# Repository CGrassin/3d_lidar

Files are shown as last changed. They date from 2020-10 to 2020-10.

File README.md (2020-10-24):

# 3D Lidar scanner

Lidars (LIgh Detection And Ranging) measure distances by illuminating the target with laser light and measuring the reflection with a sensor.

Link to the article: http://charleslabs.fr/en/project-3D+Lidar+Scanner+MK2

This is my 3D Lidar:
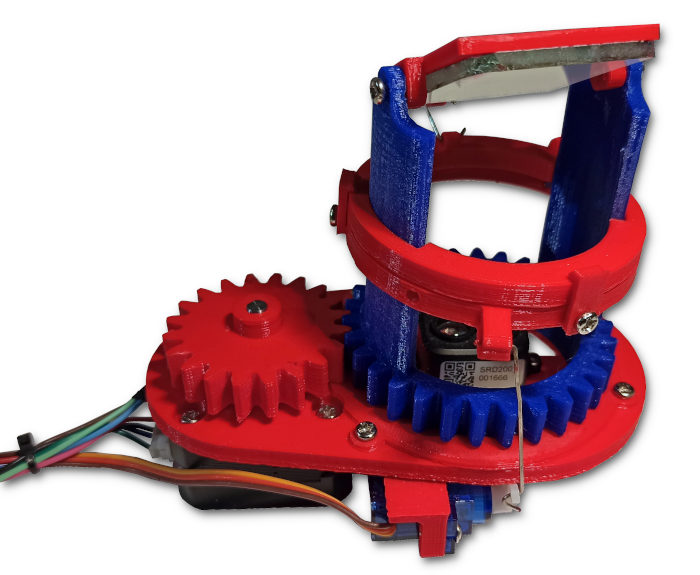
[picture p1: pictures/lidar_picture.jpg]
Picture of the 3D lidar


This repository contains the source files to build it:
* Mechanical: STL files for 3D-printing, linkages bending patterns and SolidWorks source files,
* Electronics: circuit diagram,
* Arduino code: the Arduino project for the micro-controller,
* Processing code: the LidarViewer Processing sketch.

## BOM

This is the projects' BOM:

| Quantity | Item | Total cost |
|---|---|---|
| 1 | STM32F103 board | $2 |
| 1 | Mini 360 DC Buck Converter | $1 |
| 1 | DRV8825 Stepper Motor Driver | $0.9 |
| 1 | TF-Luna LiDAR Range Finder Sensor Module | $20 |
| 1 | 17HS4023 stepper motor | $7.3 |
| 2 | 9g Sg90 Miniature Servo Motor | $2.6 |
| 1 | USB 2.0 to UART Serial Converter Module  | $1 |
| 15 | M3×6mm screw | $2 |
| 2 | M2.5 screw | $1 |
| / | PLA filament | About $3 |
| 1 | 40&times;40 piece of mirror | / |
| 1 | Breadboard | $1 |

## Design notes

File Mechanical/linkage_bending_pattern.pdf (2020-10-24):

# Linkages bending pattern

Servo linkage x2

40mm

5mm

3mm
3mm
Mirror linkage

12mm

10mm

10mm

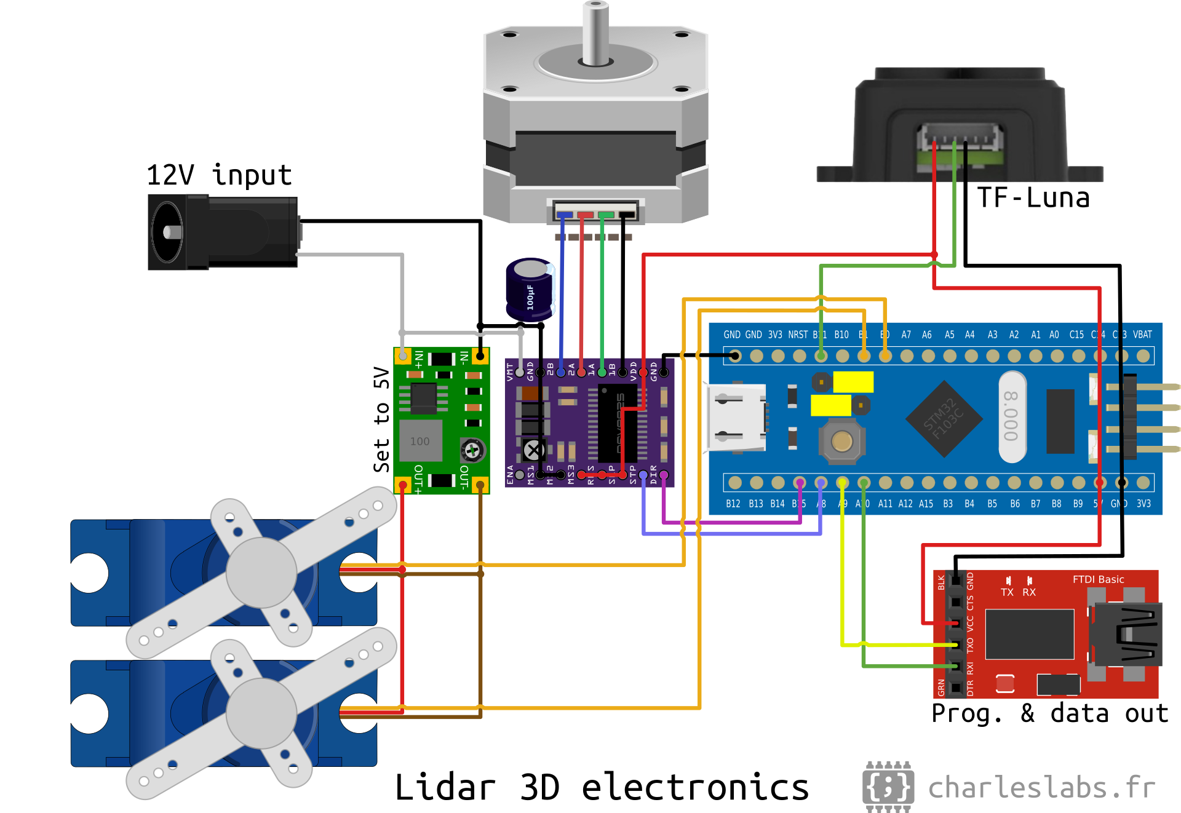
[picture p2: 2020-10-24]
Electronics/lidar_electronics.png

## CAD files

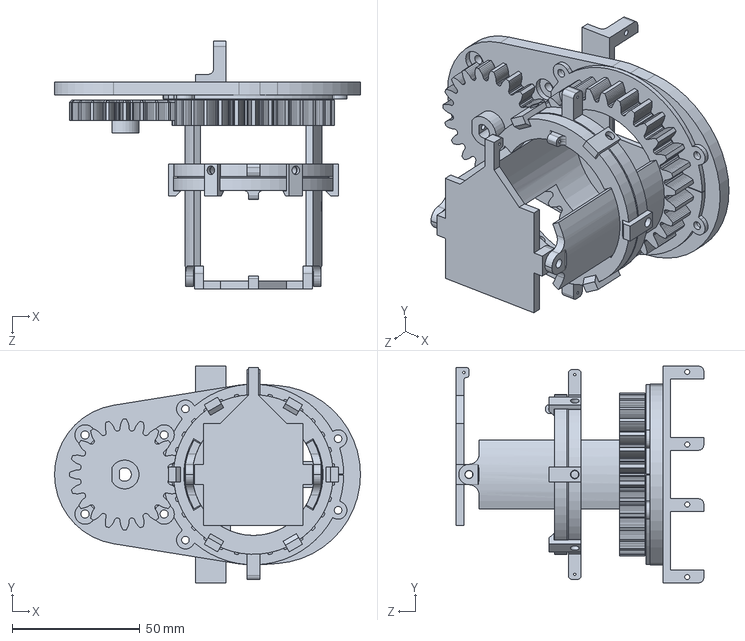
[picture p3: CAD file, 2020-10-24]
Mechanical/LidarMK2.SLDPRT
120.0 x 85.0 x 97.1 mm

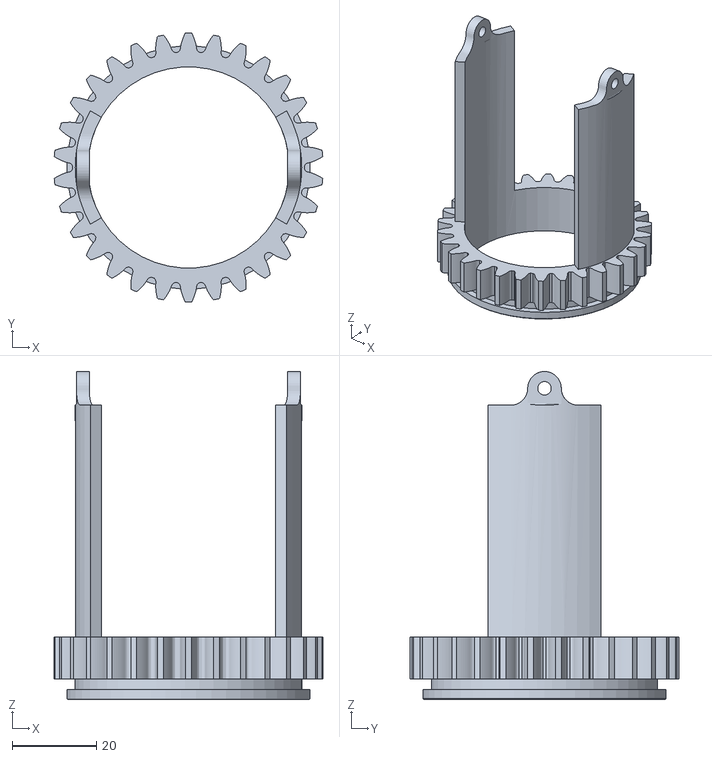
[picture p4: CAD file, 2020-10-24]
Mechanical/STL files/LidarMK2-Rotor.STL
63.8 x 64.0 x 77.9

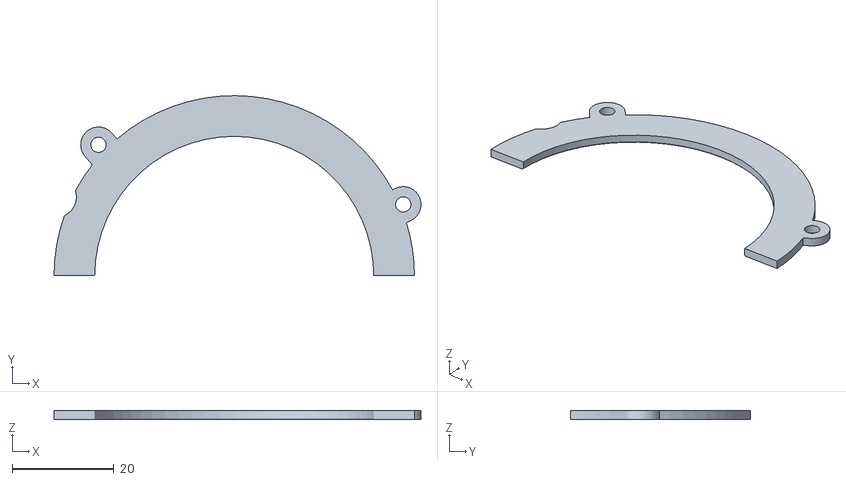
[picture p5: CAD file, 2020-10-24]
Mechanical/STL files/LidarMK2-Rotor _holder.STL
72.1 x 35.3 x 1.69

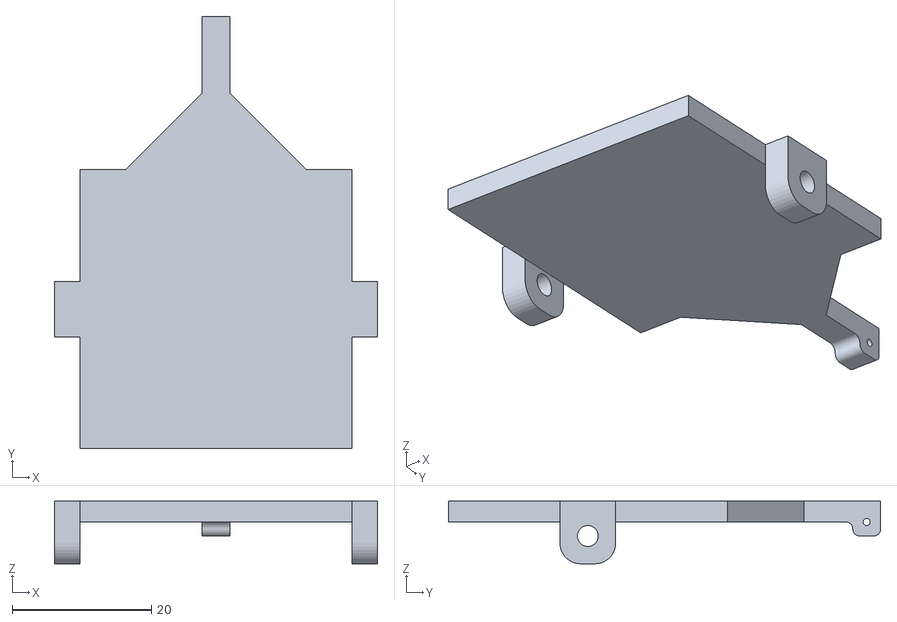
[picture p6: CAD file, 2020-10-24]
Mechanical/STL files/LidarMK2-Mirror.STL
46.3 x 62.0 x 9.00

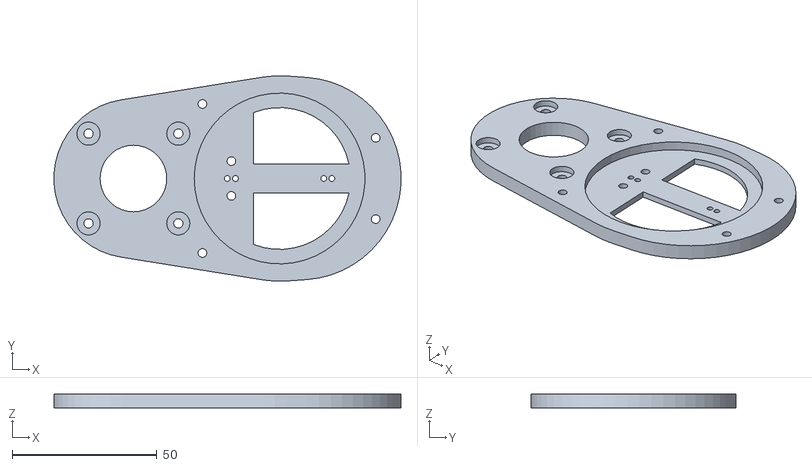
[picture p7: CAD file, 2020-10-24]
Mechanical/STL files/LidarMK2-Base.STL
119.9 x 70.9 x 5.00

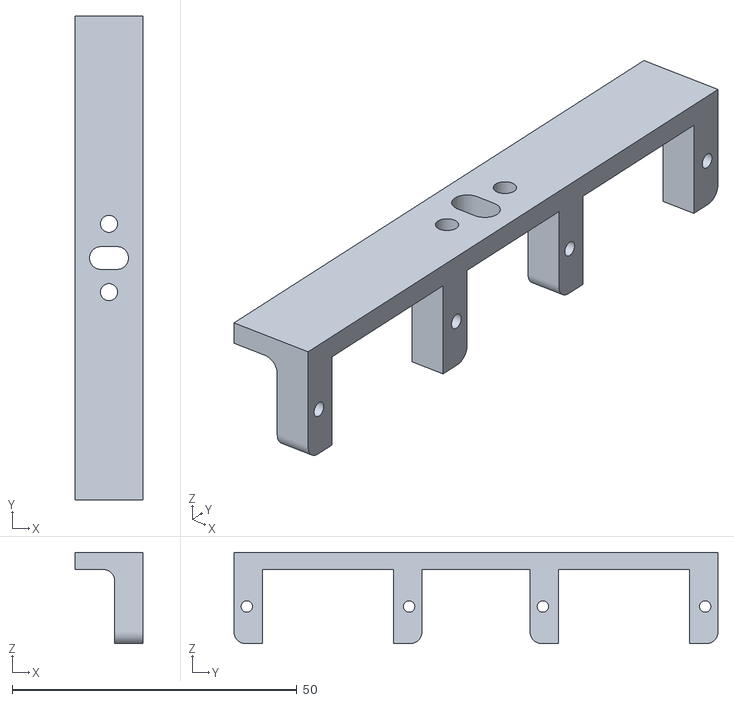
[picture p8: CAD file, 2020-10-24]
Mechanical/STL files/LidarMK2-Servos.STL
12.0 x 85.0 x 16.0

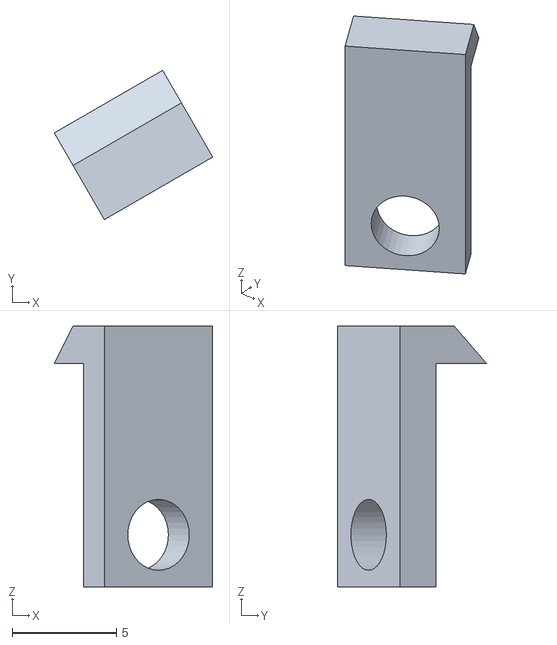
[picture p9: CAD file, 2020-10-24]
Mechanical/STL files/LidarMK2-Ring_link.STL
7.60 x 7.16 x 12.5

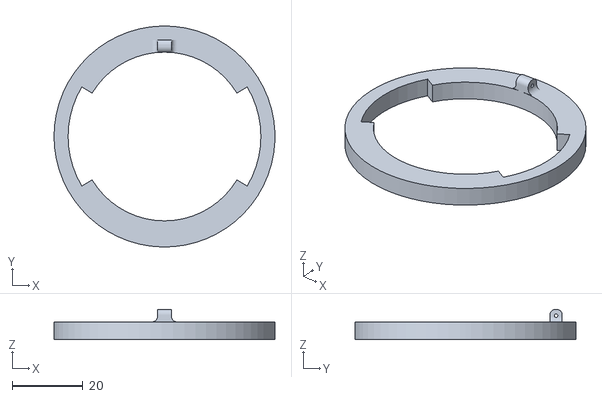
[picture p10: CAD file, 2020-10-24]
Mechanical/STL files/LidarMK2-Ring_top.STL
62.6 x 62.6 x 8.50

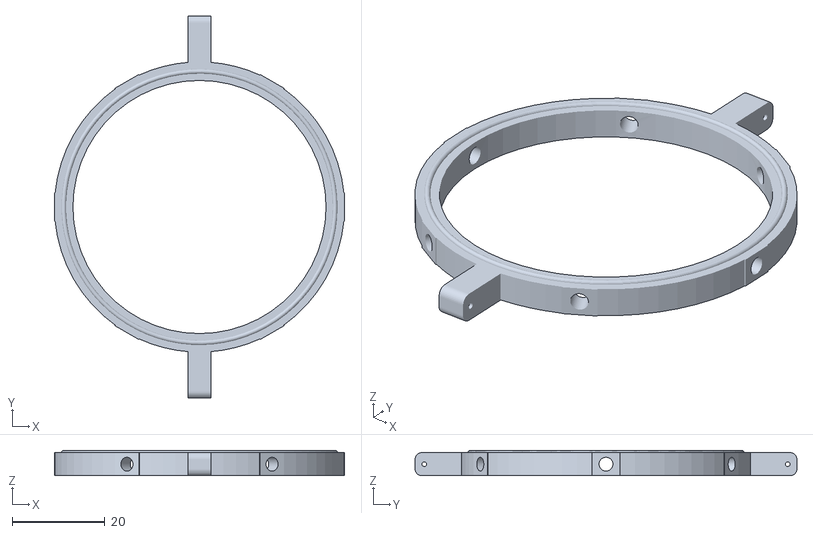
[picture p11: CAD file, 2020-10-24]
Mechanical/STL files/LidarMK2-Ring_bot.STL
62.6 x 82.4 x 5.50

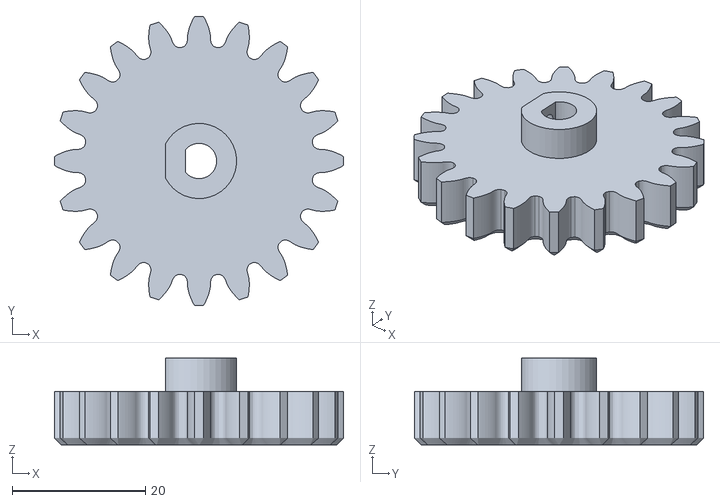
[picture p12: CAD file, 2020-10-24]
Mechanical/STL files/LidarMK2-GearMotor.STL
43.4 x 43.4 x 13.0

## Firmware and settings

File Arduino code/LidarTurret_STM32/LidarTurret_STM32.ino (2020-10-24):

// Includes
#include <Servo.h>

// TF-Mini or TF-Luna
#define TFMINI_BAUDRATE 115200 // bauds
#define TFMINI_DATARATE 10.0f // ms
int distance = 0;
int strength = 0;
float temp = 0;

// Servos
Servo servo_g, servo_d;
#define SERVO_G_PIN PB0
#define SERVO_D_PIN PB1
#define SERVO_POS_NEUTRAL 90
#define SERVO_POS_MIN SERVO_POS_NEUTRAL - 40
#define SERVO_POS_MAX SERVO_POS_NEUTRAL + 40
int servo_angle = SERVO_POS_MIN; // current servo pos

// Stepper
#define DIR_PIN PB15 
#define STEP_PIN PA8
#define PULSE_PER_REV 2400 // PPR_motor * Gear_reduction * Microstepping = 200*3/2*16
#define TIME_PER_REV 500.0f // ms
const int TIME_PER_PULSE = (TIME_PER_REV * 1000.0f)/ PULSE_PER_REV; // us
const int PULSE_PER_DATAPOINT = (TFMINI_DATARATE * 1000.0f) / TIME_PER_PULSE;

// External communication
#define EXTERNAL_BAUDRATE 115200 // bauds
char serial_buffer[15];
float theta,phi,rho;

// the setup function runs once when you press reset or power the board
void setup() {
  // Stepper
  pinMode(DIR_PIN, OUTPUT);
  pinMode(STEP_PIN, OUTPUT);
  digitalWrite(DIR_PIN,HIGH);
  
  // Servos
  servo_g.attach(SERVO_G_PIN);
  servo_d.attach(SERVO_D_PIN);
  servo_pos(servo_angle);
  
  // Serial ports
  Serial.begin(EXTERNAL_BAUDRATE); // USB
  Serial3.begin(TFMINI_BAUDRATE); // TF mini
  flushSerial3();
  
  // Center servos
  //servo_pos(SERVO_POS_MAX   );
  //for(;;){}
}

// Scanning fuction. Adapt to your needs!
uint16_t pulses = 0;
int8_t servo_dir = 1;
int8_t offset = 0;
void loop() {
  digitalWrite(STEP_PIN, HIGH);
  delayMicroseconds(TIME_PER_PULSE);
  digitalWrite(STEP_PIN, LOW);
  delayMicroseconds(TIME_PER_PULSE);
  pulses ++;

  if((pulses + offset)%PULSE_PER_DATAPOINT == 0){
    getTFminiData(&distance, &strength, &temp);
    send_pos();
  }

  if(pulses == PULSE_PER_REV) {
  pulses = 0;
  servo_angle += servo_dir;
  if(servo_angle > SERVO_POS_MAX || servo_angle < SERVO_POS_MIN){
    servo_dir = -servo_dir;
  }
  servo_pos(servo_angle);
  }
}

// Send X Y Z STRENGTH to the computer
// @TODO: reverse kinematics
void send_pos(){
  if(distance == 0) return;
  
  theta = (float)pulses*360.0f/PULSE_PER_REV; //compute angle from motor pulses
  theta *= PI / 180.0f; // convert to radians
  
  phi = (float)servo_angle*-0.3f+71; // compute angle from servo geometry
  phi = 2*phi - 90.0f; // compute mirror bounce angle
  phi *= PI / 180.0f; // convert to radians
  
  rho = distance - 5.5f; // rho is the LIDAR distance
  
  sprintf(serial_buffer,"%d\t%d\t%d\t%d\n\0",(int)(rho*cos(phi)*cos(theta)),(int)(rho*cos(phi)*sin(theta)),(int)(rho*sin(phi)),strength);
  Serial.print(serial_buffer);
}

// Move both servos to change the mirror angle
void servo_pos(int angle){
  if(angle > SERVO_POS_MAX || angle < SERVO_POS_MIN)
  return;
    servo_g.write(180 - angle);
    servo_d.write(angle);
}

// Fetchs data from the Lidar
void getTFminiData(int* distance, int* strength, float* temp) {
  static char i = 0;
  char j = 0;
  int checksum = 0;
  static int rx[9];
  while(1){
  if(Serial3.available())
  { 
      rx[i] = Serial3.read();
//      Serial.println(rx[i],HEX);
      if(rx[0] != 0x59) {
        i = 0;
      } else if(i == 1 && rx[1] != 0x59) {
        i = 0;
      } else if(i == 8) {
        for(j = 0; j < 8; j++) {
          checksum += rx[j];
        }
        if(rx[8] == (checksum % 256)) {
          *distance = rx[2] + rx[3] * 256;
          *strength = rx[4] + rx[5] * 256;
          *temp = (rx[6] + rx[7] * 256.0f)/8 - 256;
        }
        i = 0;
        break;
      } else
      {
        i++;
      }
    }
  }
  flushSerial3();
}

// Flushes the INPUT serial buffer
void flushSerial3(){
  while(Serial3.available()){Serial3.read();}
}

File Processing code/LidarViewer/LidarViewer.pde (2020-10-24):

// LidarViewer.pde Processing sketch
// http://www.charleslabs.fr/en/project-3D+Lidar+Scanner+MK2

// Load sketch into Processing, available from:
// https://processing.org/
// You also need to install the PeasyCam library: Sketch > Import Library... > Add Library... > Search for "peasycam"

// This software read coordinates of the Arduino Lidar 
// (format: "X Y Z") and displays it as a 3D point cloud that you
// can move around using the mouse.
// Press 's' to save the cloud as a text file.
// Press 'x' to clear the points.

import processing.serial.*;
import peasy.*;
import java.io.FileWriter;
import javax.swing.JOptionPane;

Serial serial;
PeasyCam cam;
final float angleIncrement=0.1f;

ArrayList<PVector> pointList;

final int SERIAL_SPEED = 115200;

void setup() {
  size(1760 , 990, P3D);
  //surface.setResizable(true);
  
  surface.setTitle("3D Lidar Viewer");
  
  colorMode(RGB, 255, 255, 255);
  pointList = new ArrayList<PVector>();
  
  // PeasyCam
  cam = new PeasyCam(this, 500);
  cam.rotateZ(-3.1415/4);
  cam.rotateX(-3.1415/4);
  
  // Serial Port (added dialog)
  try {
    if (Serial.list().length == 0) {
      println("No serial device connected");
      exit();
    }
    else if (Serial.list().length == 1) {
      // only one device, select it (or try...)
      serial = new Serial(this, Serial.list()[0], SERIAL_SPEED);
    }
    else {
      // more than 1, show dialog
      String[] ports = Serial.list();
      
      String selection = (String) JOptionPane.showInputDialog(null,
          "Select the serial port that corresponds to the Lidar:",
          "Select serial port",
          JOptionPane.PLAIN_MESSAGE,
          null,
          ports,
          ports[ports.length-1]);
      
      if (selection == null || selection.isEmpty()) 
        exit();

      serial = new Serial(this, selection, SERIAL_SPEED); // change baud rate to your liking
    }
  }
  catch (Exception e) { 
    println("Not able to connect to serialPort (error:"+e.getClass().getName()+" " + e.getMessage() + ")");
    exit();
  }
}

void draw() {
  // Prepare window & drawing
  perspective();
  background(33);
  stroke(255,255,255);
  sphere(0.5f);
  fill(50);
  ellipse(0, 0, 10, 10);

  //Read Serial Port (if we can)
  String serialString = serial.readStringUntil('\n');
  if (serialString != null) {
    String[] coordinates = split(serialString, '\t');
    if (coordinates.length == 4) {
      pointList.add(new PVector(float(coordinates[0]), float(coordinates[1]), float(coordinates[2])));
    }
  }
 
  // Draw the actual point cloud
  for (int index = 0; index < pointList.size(); index++) {
    PVector v = pointList.get(index);
    if (index == pointList.size() - 1) {
      // Draw a line between Lidar and last point
      stroke(255, 15, 15);
      line(0, 0, 0, v.x,v.y,v.z);
    }
    // Draw point with a variable color
    stroke(255-v.z, 255-v.y, 255-v.x);
    point(v.x, v.y, v.z);
  }
}

// Handle keyboard events : movement, save & clear all points.
void keyReleased() {
  if (key =='x') {
    // erase all points
    pointList.clear();
  } else if(key == 's'){
    selectOutput("Select a file to write to:", "saveToFile");
  }
  else if (key == CODED) {
    if (keyCode == UP) {
      cam.rotateX(angleIncrement);
    } else if (keyCode == DOWN) {
      cam.rotateX(-angleIncrement);
    }else if (keyCode == LEFT) {
      cam.rotateY(angleIncrement);
    }else if (keyCode == RIGHT) {
      cam.rotateY(-angleIncrement);
    }
  }
}

// Function to save the point cloud in the Processing install directory
void saveToFile(final File selection){
  final String fileName = selection.getAbsolutePath();
  PrintWriter pw = null;
 
  try{
    pw = new PrintWriter(new FileWriter(fileName,true));
    for(int i=0;i<pointList.size();i++)
      pw.println((int)pointList.get(i).x + " " + 
                  (int)pointList.get(i).y + " " +
                  (int)pointList.get(i).z);
  }
  catch(Exception e){
  }
  finally {
    if(pw != null) pw.close();
  }
}
